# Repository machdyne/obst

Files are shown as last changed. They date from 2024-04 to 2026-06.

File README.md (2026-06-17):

# Obst Computer

Obst is an FPGA computer designed by Lone Dynamics Corporation.

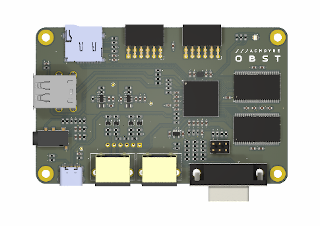
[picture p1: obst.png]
Obst


This repo will contain schematics, PCB layouts, pinouts, a 3D-printable case, example gateware and documentation.

Find more information on the [Obst product page](https://machdyne.com/product/obst-computer/).

## Programming Obst

Obst has a JTAG interface and ships with a [DFU bootloader](https://github.com/machdyne/tinydfu-bootloader) that allows the included flash [MMOD](https://machdyne.com/product/mmod) to be programmed over the USB-C port.

### DFU

The DFU bootloader is available for 5 seconds after power-on, issuing a DFU command during this period will stop the boot process until the DFU device is detached. If no command is received the boot process will continue and the user gateware will be loaded.

Install [dfu-util](http://dfu-util.sourceforge.net) (Debian/Ubuntu):

```
$ sudo apt install dfu-util
```

Update the user gateware on the flash MMOD:

```
$ sudo dfu-util -a 0 -D image.bit
```

Detach the DFU device and continue the boot process:

```
$ sudo dfu-util -a 0 -e
```

It is possible to update the bootloader itself using DFU but you shouldn't attempt this unless you have a JTAG programmer (or another method to program the MMOD) available, in case you need to restore the bootloader.

### JTAG

These examples assume you're using a "USB Blaster" JTAG cable, see the header pinout below. You will need to have [openFPGALoader](https://github.com/trabucayre/openFPGALoader) installed.

Program the configuration SRAM:

```
openFPGALoader -c usb-blaster image.bit
```

Program the flash MMOD:

```
openFPGALoader -f -c usb-blaster images/bootloader/tinydfu_obst.bit
```

## Blinky 

Building the blinky example requires [Yosys](https://github.com/YosysHQ/yosys), [nextpnr-ecp5](https://github.com/YosysHQ/nextpnr) and [Project Trellis](https://github.com/YosysHQ/prjtrellis).

Assuming they are installed, you can simply type `make` to build the gateware, which will be written to output/blinky.bin. You can then use [openFPGALoader](https://github.com/trabucayre/openFPGALoader) or dfu-util to write the gateware to the device.

## Zucker SOC

Obst can be used with [Zucker SOC](https://github.com/machdyne/zucker).

## JTAG Header

The 3.3V JTAG header can be used to program the FPGA SRAM as well as the MMOD flash memory. It can also be used to provide power (5V) to the board.

```
2 4 6
1 3 5
```

| Pin | Signal |
| --- | --- |
| 1 | TCK |
| 2 | TDI |
| 3 | TDO |
| 4 | TMS |
| 5 | 5V0 |
| 6 | GND |

## Board Revisions

| Revision | Notes |
| --- | ----- |
| V0A | Initial production version |
| V0B | Latest production version |

## License

The contents of this repo are released under the [Lone Dynamics Open License](LICENSE.md) with the following exceptions:

- The KiCad design files contain parts of the [kicad-pmod](https://github.com/mithro/kicad-pmod) library which is released under the [Apache License, Version 2.0](https://www.apache.org/licenses/LICENSE-2.0.html).

- The KiCad design files may contain symbols and footprints released under other licenses; please contact us if we've failed to give proper attribution.

Note: You can use these designs for commercial purposes but we ask that instead of producing exact clones, that you either replace our trademarks and logos with your own or add your own next to ours.

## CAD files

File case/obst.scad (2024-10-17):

/*
 * Obst Case
 * Copyright (c) 2024 Lone Dynamics Corporation. All rights reserved.
 *
 * required hardware:
 *  - 4 x M3 x 30mm countersunk bolts
 *  - 4 x M3 nuts
 * 
 */

$fn = 100;

board_width = 62;
board_thickness = 1.404;
board_length = 100;
board_height = 1.6;
board_spacing = 2;

wall = 1.5;

translate([2,2,-1.6]) mdr_board();

translate([0,0,0])
	mdr_case_top();

translate([0,0,-10])
	mdr_case_bottom();

module mdr_board() {
	
	difference() {
		union() {
			color([0,0.5,0])
				roundedcube(board_width,board_length,board_thickness, 4);

		}
		translate([4, 4, -1]) cylinder(d=3.2, h=100);
		translate([4, 96, -1]) cylinder(d=3.2, h=100);
		translate([58, 4, -1]) cylinder(d=3.2, h=100);
		translate([58, 96, -1]) cylinder(d=3.2, h=100);
	}	
		
}

module mdr_case_top() {

		translate([0,25,19])
				rotate([90,0,270])
					translate([-62.5,-10,0])
						linear_extrude(1)
							text("O B S T", size=4, halign="center",
								font="Liberation Sans:style=Bold");

		// addl supports
		translate([62,30.5+(14.5/2)+2,0]) cube([3.25,4,20]);
		translate([62,49.5+(14.5/2)+1.5,0]) cube([3.25,4.425,20]);
		translate([62,22.25,0]) cube([3.25,3,20]);

		translate([0,53.075,0]) cube([3.25,6.875,20]);
		translate([0,28.5,0]) cube([3.25,8.575,20]);

		translate([35,0,0]) cube([8.25,2.5,20]);
				
		translate([2,2,0]) {
			difference() {
				union() {
					translate([0,0,0]) cube([10,9,20]);
					translate([0,91.65,0]) cube([10,8.5,20]);
					translate([55,0,0]) cube([8,7.5,20]);
					translate([52,91.65,0]) cube([10,8.5,20]);
				}		

				// bolt holes
				translate([4,4,0]) cylinder(d=3.2, h=50);
				translate([4,96,0]) cylinder(d=3.2, h=50);
				translate([58,4,0]) cylinder(d=3.2, h=50);
				translate([58,96,0]) cylinder(d=3.2, h=50);
				
				translate([4,4,18.5]) cylinder(d=6, h=2);
				translate([4,96,18.5]) cylinder(d=6, h=2);
				translate([58,4,18.5]) cylinder(d=6, h=2);
				translate([58,96,18.5]) cylinder(d=6, h=2);

			}

		}
	
		difference () {
			
			// body			
			union() {
				roundedcube(board_width+4,board_length+4,20,5);
			}
			
			translate([2,2,-0.01]) {
				
				translate([0,0,0]) roundedcube(board_width,board_length,20-2,5);

				// vents
				translate([66/2-(15/2)-2,104/2-2-5,15]) rotate([0,0,-10]) cube([15,1,20]);
				translate([66/2-(15/2)-2,104/2-2,15]) rotate([0,0,-10]) cube([15,1,20]);
				translate([66/2-(15/2)-2,104/2-2+5,15]) rotate([0,0,-10]) cube([15,1,20]);		
				
				// LED vents
				translate([-10,86-5,3]) cube([25,1,1]);
				translate([-10,86,3]) cube([25,1,1]);
				translate([-10,86+5,3]) cube([25,1,1]);
				
				// PMODA
				translate([-10,43.075-(16/2),0]) cube([25,16,5.1]);

				// PMODB
				translate([-10,65.95-(16/2),0]) cube([25,16,5.1]);

				// sd card
				translate([-10,19-(15/2),0])
					cube([15,15,3]);

				// usb host
				translate([25.5-(15/2),-5,0])
					cube([15,10,16.25]);
				
				// audio jack
				translate([44.5-(6.5/2),-5,0])
					cube([6.5,10,6]);
	
				// VGA
				translate([55,76.175-(31/2),0]) cube([30,31,12.5]);
	
				// PS/2
				translate([55,30.5-(14.5/2),-2]) cube([30,14.5,13+2]);
				translate([55,49-(14.5/2),-2]) cube([30,14.5,13+2]);
				
				// usb-c
				translate([55,14-(9.5/2),0])
					cube([10,9.5,3.25]);

				// bolt holes
				translate([4,4,0]) cylinder(d=3.2, h=50);
				translate([4,96,0]) cylinder(d=3.2, h=50);
				translate([58,4,0]) cylinder(d=3.2, h=50);
				translate([58,96,0]) cylinder(d=3.2, h=50);
				
				translate([4,4,18.5]) cylinder(d=6, h=2);
				translate([4,96,18.5]) cylinder(d=6, h=2);
				translate([58,4,18.5]) cylinder(d=6, h=2);
				translate([58,96,18.5]) cylinder(d=6, h=2);
		
			}

		}				
		
}

module mdr_case_bottom() {

		difference () {
			
			union() {
				roundedcube(board_width+4,board_length+4,10,5);
			}
						
			translate([2,2,0]) {
				
				translate([8,-0.1,2]) roundedcube(board_width-8-8,board_length+0.2,10,5);
				translate([-0.25,8,2]) roundedcube(board_width+0.5,board_length-16,10,5);
			
				translate([-0.125,-0.125, 10-1.65])
					roundedcube(board_width+0.25,board_length+0.25, 10, 4);
				
				// bolt holes
				translate([4,4,0]) cylinder(d=3.2, h=50);
				translate([4,96,0]) cylinder(d=3.2, h=50);
				translate([58,4,0]) cylinder(d=3.2, h=50);
				translate([58,96,0]) cylinder(d=3.2, h=50);

				// nut holes
				translate([4,4,-1.75]) cylinder(d=7, h=4.5, $fn=6);
				translate([4,96,-1.75]) cylinder(d=7, h=4.5, $fn=6);
				translate([58,4,-1.75]) cylinder(d=7, h=4.5, $fn=6);
				translate([58,96,-1.75]) cylinder(d=7, h=4.5, $fn=6);


			}

		}
		
}

// https://gist.github.com/tinkerology/ae257c5340a33ee2f149ff3ae97d9826
module roundedcube(xx, yy, height, radius)
{
    translate([0,0,height/2])
    hull()
    {
        translate([radius,radius,0])
        cylinder(height,radius,radius,true);

        translate([xx-radius,radius,0])
        cylinder(height,radius,radius,true);

        translate([xx-radius,yy-radius,0])
        cylinder(height,radius,radius,true);

        translate([radius,yy-radius,0])
        cylinder(height,radius,radius,true);
    }
}

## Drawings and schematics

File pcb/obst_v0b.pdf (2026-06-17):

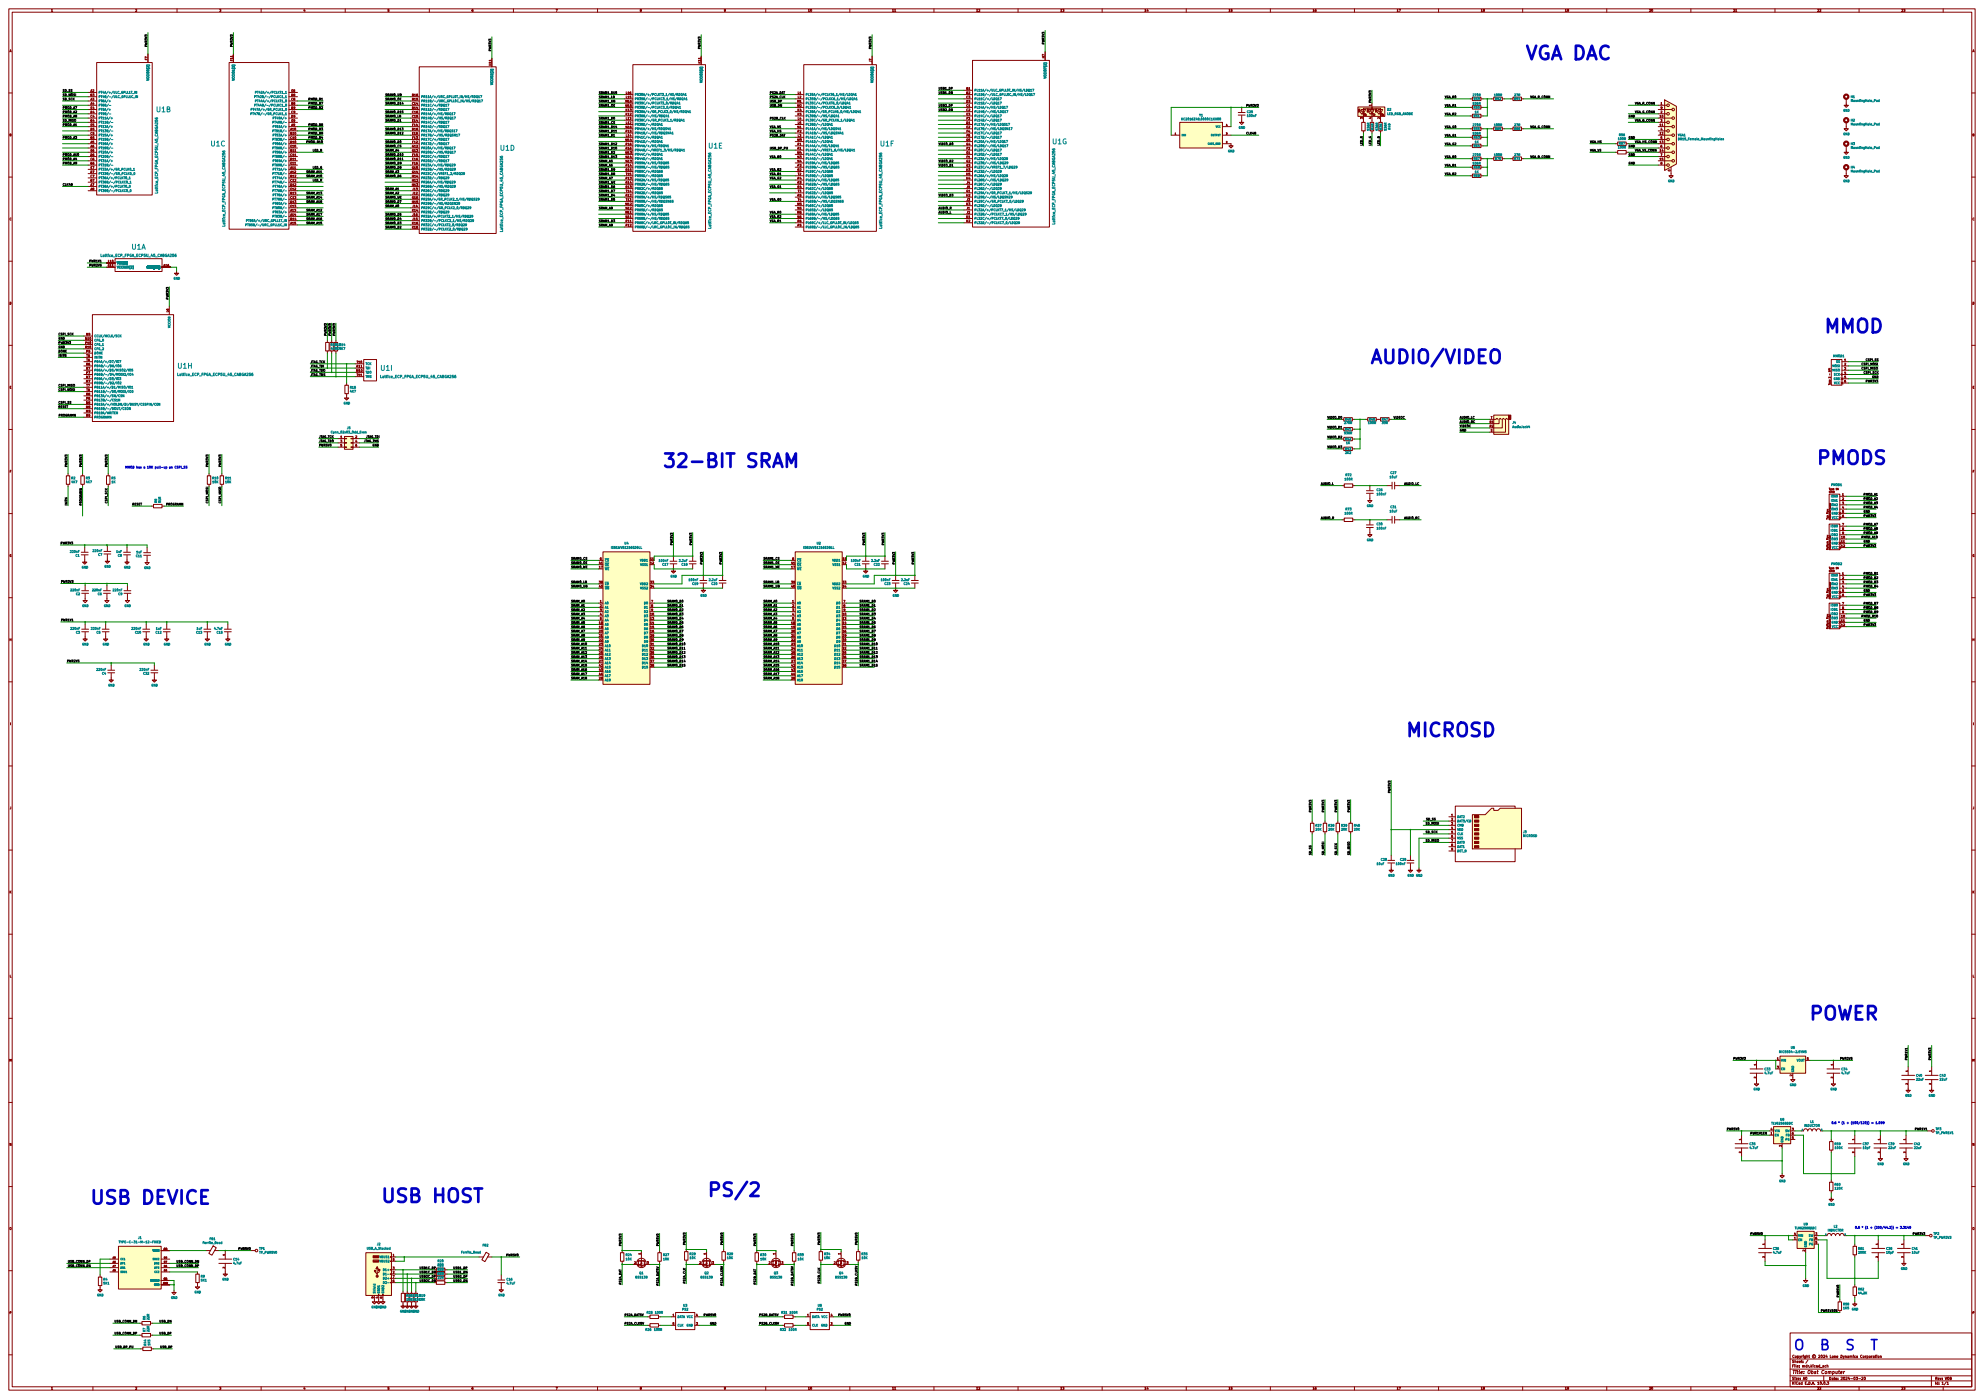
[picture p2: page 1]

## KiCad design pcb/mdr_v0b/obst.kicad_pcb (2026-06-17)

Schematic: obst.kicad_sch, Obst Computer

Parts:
C1, C2, C3, C4, C5, C6, C7, C9, C10, C32: 220nF; C_0603_1608Metric
C8, C11, C12, C13: 1uF; C_0603_1608Metric
C14, C15, C16, C33, C34, C35, C36: 4.7uF; C_0603_1608Metric
C17, C19, C21, C23, C25, C26, C29, C30: 100nF; C_0603_1608Metric
C18, C20, C22, C24: 2.2uF; C_0603_1608Metric
C27, C28, C31, C41: 10uF; C_0603_1608Metric
C37, C38: 10pF; C_0603_1608Metric
C39, C40, C42, C43: 22uF; C_0603_1608Metric
D2: LED_RGB_ANODE; LED_RGB_0606_CHANZON
FB1, FB2: Ferrite_Bead; R_0603_1608Metric
H1, H2, H3, H4: MountingHole_Pad; MountingHole_3.2mm_M3_Pad
J1: TYPE-C-31-M-12-FIXED; USB_C_Receptacle_HRO_TYPE-C-31-M-12-BIG-PADS; PARTREV A
J2: USB_A_Stacked; USB_A_Wuerth_61400826021_Horizontal_Stacked
J3: MICROSD; SDCARD
J4: AudioJack4; Jack_3.5mm_PJ320D_Horizontal
J5: Conn_02x03_Odd_Even; PinHeader_2x03_P2.54mm_Vertical
L1, L2: INDUCTOR; L_0805_2012Metric
MMOD1: PMOD-Device-x1-Type-2-SPI; MMOD_Host_Socket
PMOD1, PMOD2: PMOD-Device-x2-Type-1A-GPIO; PMOD_2x06_HOST
Q1, Q2, Q3, Q4: BSS138; SOT-323_SC-70
R2, R3, R12, R13, R14, R15: 4K7; R_0603_1608Metric
R4, R9: 5K1; R_0603_1608Metric
R5, R42, R51, R64, R69: 1K; R_0603_1608Metric
R6, R7, R20, R21, R22, R23: 22R; R_0603_1608Metric
R8: 51R; R_0603_1608Metric
R10, R11, R24, R27, R28, R29, R30, R33, R34, R35: 10K; R_0603_1608Metric
R16, R17, R18, R19: 15K; R_0603_1608Metric
R25, R26, R31, R32, R46, R52, R56, R57, R65, R70, R72, R73: 100R; R_0603_1608Metric
R36, R41, R48, R49, R50, R63, R68: 536R; R_0603_1608Metric
R37, R38, R39, R45: 20K; R_0603_1608Metric
R40, R53, R55, R67: 270R; R_0603_1608Metric
R43: 2K2; R_0603_1608Metric
R44, R58: 1K5; R_0603_1608Metric
R47: 33R; R_0603_1608Metric
R54, R66, R71: 27R; R_0603_1608Metric
R59: 100K; R_0603_1608Metric
R60: 120K; R_0603_1608Metric
R61: 200K; R_0603_1608Metric
R62: 44.2K; R_0603_1608Metric
TP1: TP_PWR5V0; TestPoint_THTPad_D1.0mm_Drill0.5mm
TP2: TP_PWR3V3; TestPoint_THTPad_D1.0mm_Drill0.5mm
TP3: TP_PWR1V1; TestPoint_THTPad_D1.0mm_Drill0.5mm
U1: Lattice_ECP_FPGA_ECP5U_45_CABGA256; BGA-256_14.0x14.0mm_Layout16x16_P0.8mm_Ball0.45mm_Pad0.32mm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
U2, U4: IS61WV51216EDBLL; TSOP-II-44_10.16x18.41mm_P0.8mm
U3, U5: PS2; MINI-DIN-6-FULL-SHIELD
U6: MIC5504-2.5YM5; SOT-23-5
U8, U9: TLV62568DDC; SOT-23-6
VGA1: DB15_Female_MountingHoles; DSUB-15-HD_Female_Horizontal_P2.29x1.98mm_EdgePinOffset3.03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
Y1: KC2016Z48.0000C1KX00; OSC_KC2016Z13.5600C1KX00; PARTREV November 2020

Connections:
/AUDIO_L: R72.1, U1.J2 (PL32B/-/PCLKC7_1/HS/LDQ29)
/AUDIO_LC: C27.2, J4.T
/AUDIO_R: R73.1, U1.J1 (PL32A/+/PCLKT7_1/HS/LDQ29)
/AUDIO_RC: C31.2, J4.R1
/CLK48: U1.A7 (PT38A/+/PCLKT0_0), Y1.3 (OUTPUT)
/CSPI_MISO: MMOD1.3 (MISO), R11.2, U1.T7 (PB11A/+/D1/MISO/IO1)
/CSPI_MOSI: MMOD1.2 (MOSI), R10.2, U1.T8 (PB11B/-/D0/MOSI/IO0)
/CSPI_SCK: MMOD1.4 (SCK), R5.2, U1.N9 (CCLK/MCLK/SCK)
/CSPI_SS: MMOD1.1 (SS), U1.N8 (PB15A/+/HOLDN/DI/BUSY/CSSPIN/CEN)
/DONE: U1.P9 (DONE)
/INITN: R2.2, U1.T9 (INITN)
/JTAG_TCK: J5.1, R15.1, U1.T10 (TCK)
/JTAG_TDI: J5.2, R12.2, U1.R11 (TDI)
/JTAG_TDO: J5.3, R13.2, U1.M10 (TDO)
/JTAG_TMS: J5.4, R14.2, U1.T11 (TMS)
/LED_B: R49.1, U1.B11 (PT58A/+)
/LED_G: R36.1, U1.A11 (PT71A/+)
/LED_R: R48.1, U1.C12 (PT74B/-)
/PMOD_A1: PMOD1.1 (IOA0), U1.E5 (PT13A/+)
/PMOD_A2: PMOD1.2 (IOA1), U1.D4 (PT9B/-)
/PMOD_A3: PMOD1.3 (IOA2), U1.B5 (PT15B/-)
/PMOD_A4: PMOD1.4 (IOA3), U1.C6 (PT31A/+)
/PMOD_A7: PMOD1.7 (IOB0), U1.E4 (PT9A/+)
/PMOD_A8: PMOD1.8 (IOB1), U1.C4 (PT11A/+)
/PMOD_A9: PMOD1.9 (IOB2), U1.B6 (PT31B/-)
/PMOD_A10: PMOD1.10 (IOB3), U1.D6 (PT20B/-)
/PMOD_B1: PMOD2.1 (IOA0), U1.C8 (PT44A/+/PCLKT1_0)
/PMOD_B2: PMOD2.2 (IOA1), U1.B9 (PT47A/+/GR_PCLK1_0)
/PMOD_B3: PMOD2.3 (IOA2), U1.A10 (PT51B/-)
/PMOD_B4: PMOD2.4 (IOA3), U1.C10 (PT53B/-)
/PMOD_B7: PMOD2.7 (IOB0), U1.B8 (PT44B/-/PCLKC1_0)
/PMOD_B8: PMOD2.8 (IOB1), U1.A9 (PT51A/+)
/PMOD_B9: PMOD2.9 (IOB2), U1.B10 (PT53A/+)
/PMOD_B10: PMOD2.10 (IOB3), U1.D10 (PT56A/+)
/PROGRAMN: R3.2, R8.2, U1.R9 (PROGRAMN)
/PS2A_CLK: Q2.2 (S), R28.2, U1.L2 (PL35B/-/PCLKC6_1/HS/LDQ41)
/PS2A_CLK5V: Q2.3 (D), R26.1, R29.2
/PS2A_DAT: Q1.2 (S), R24.2, U1.L1 (PL35A/+/PCLKT6_1/HS/LDQ41)
/PS2A_DAT5V: Q1.3 (D), R25.1, R27.2
/PS2B_CLK: Q4.2 (S), R34.2, U1.L4 (PL38C/+/GR_PCLK6_1/LDQ41)
/PS2B_CLK5V: Q4.3 (D), R32.1, R35.2
/PS2B_DAT: Q3.2 (S), R30.2, U1.L3 (PL41C/+/LDQ41)
/PS2B_DAT5V: Q3.3 (D), R31.1, R33.2
/PWR1V1: C3.2, C5.2, C10.2, C12.2, C13.2, C15.2, C37.1, C39.1, C40.1, C42.1, L1.2, R59.1, TP3.1, U1.G6 (VCC[6]), U1.G7 (VCC[6]), U1.G9 (VCC[6]), U1.L8 (VCC[6]), U1.L9 (VCC[6]), U1.L10 (VCC[6])
/PWR1V1EN: R58.2, U8.1 (EN), U9.5 (PG)
/PWR2V5: C4.2, C32.2, C34.1, U1.G11 (VCCAUX[2]), U1.L7 (VCCAUX[2]), U6.5 (VOUT)
/PWR3V3: C1.2, C2.2, C6.2, C7.2, C8.2, C9.2, C11.2, C17.2, C18.2, C19.2, C20.2, C21.2, C22.2, C23.2, C24.2, C25.1, C28.1, C29.1, C33.1, C38.1, C41.1, C43.1, D2.1 (A), J3.4 (VDD), L2.2, MMOD1.6 (VCC), PMOD1.6 (VCC), PMOD1.12 (VCC), PMOD2.6 (VCC), PMOD2.12 (VCC), Q1.1 (G), Q2.1 (G), Q3.1 (G), Q4.1 (G), R2.1, R3.1, R5.1, R10.1, R11.1, R12.1, R13.1, R14.1, R24.1, R28.1, R30.1, R34.1, R37.1, R38.1, R39.1, R45.1, R61.1, TP2.1, U1.F6 (VCCIO0[2]), U1.F7 (VCCIO0[2]), U1.F10 (VCCIO1[2]), U1.F11 (VCCIO1[2]), U1.H6 (VCCIO7[2]), U1.H7 (VCCIO7[2]), U1.H11 (VCCIO2[2]), U1.J6 (VCCIO6[2]), U1.J7 (VCCIO6[2]), U1.J11 (VCCIO2[2]), U1.K11 (VCCIO3[2]), U1.L6 (VCCIO8), U1.L11 (VCCIO3[2]), U1.P10 (CFG_1), U2.11 (VDD1), U2.33 (VDD2), U4.11 (VDD1), U4.33 (VDD2), U6.1 (VIN), U6.3 (EN), Y1.1 (INH), Y1.4 (VCC)
/PWR5V0: C14.1, C16.1, C35.1, C36.1, FB1.1, FB2.1, J5.5, R27.1, R29.1, R33.1, R35.1, R58.1, TP1.1, U3.4 (VCC), U5.4 (VCC), U8.4 (VIN), U9.1 (EN), U9.4 (VIN)
/RESET: R8.1, U1.M8 (PB15B/-/DOUT/CSON)
/SD_MISO: J3.7 (DAT0), R45.2, U1.B4 (PT11B/-)
/SD_MOSI: J3.3 (CMD), R38.2, U1.B3 (PT4B/-/ULC_GPLL1C_IN)
/SD_SCK: J3.5 (CLK), R39.2, U1.A3 (PT6A/+)
/SD_SS: J3.2 (DAT3/CD), R37.2, U1.A2 (PT4A/+/ULC_GPLL1T_IN)
/SRAM0_CS: U1.G12 (PR20A/+/HS/RDQ17), U4.6 (~CS)
/SRAM0_D0: U1.F12 (PR17D/-/RDQ17), U4.7 (D0)
/SRAM0_D1: U1.E14 (PR14C/+/RDQ17), U4.8 (D1)
/SRAM0_D2: U1.K15 (PR32D/-/PCLKC2_0/RDQ29), U4.9 (D2)
/SRAM0_D3: U1.K16 (PR32C/+/PCLKT2_0/RDQ29), U4.10 (D3)
/SRAM0_D4: U1.J15 (PR32B/-/PCLKC2_1/HS/RDQ29), U4.13 (D4)
/SRAM0_D5: U1.J16 (PR32A/+/PCLKT2_1/HS/RDQ29), U4.14 (D5)
/SRAM0_D6: U1.H14 (PR23D/-/RDQ29), U4.15 (D6)
/SRAM0_D7: U1.H15 (PR29B/-/HS/RDQSN29), U4.16 (D7)
/SRAM0_D8: U1.G15 (PR23B/-/HS/RDQ29), U4.29 (D8)
/SRAM0_D9: U1.F16 (PR23A/+/HS/RDQ29), U4.30 (D9)
/SRAM0_D10: U1.F15 (PR20C/+/RDQ17), U4.31 (D10)
/SRAM0_D11: U1.E16 (PR20D/-/RDQ17), U4.32 (D11)
/SRAM0_D12: U1.E15 (PR17B/-/HS/RDQSN17), U4.35 (D12)
/SRAM0_D13: U1.D16 (PR17A/+/HS/RDQS17), U4.36 (D13)
/SRAM0_D14: U1.C14 (PR11C/+/RDQ17), U4.37 (D14)
/SRAM0_D15: U1.C16 (PR14A/+/HS/RDQ17), U4.38 (D15)
/SRAM0_LB: U1.C15 (PR14B/-/HS/RDQ17), U4.39 (~LB)
/SRAM0_OE: U1.B15 (PR11B/-/URC_GPLL0C_IN/HS/RDQ17), U4.41 (~OE)
/SRAM0_UB: U1.B16 (PR11A/+/URC_GPLL0T_IN/HS/RDQ17), U4.40 (~UB)
/SRAM0_WE: U1.G16 (PR29A/+/GR_PCLK2_1/HS/RDQS29), U4.17 (~WE)
/SRAM1_CS: U1.L12 (PR38D/-/RDQ41), U2.6 (~CS)
/SRAM1_D0: U1.L13 (PR38C/+/GR_PCLK3_1/RDQ41), U2.7 (D0)
/SRAM1_D1: U1.L14 (PR41C/+/RDQ41), U2.8 (D1)
/SRAM1_D2: U1.M13 (PR44C/+/RDQ41), U2.9 (D2)
/SRAM1_D3: U1.P11 (PR68C/+/LRC_GPLL0T_IN/RDQ65), U2.10 (D3)
/SRAM1_D4: U1.R12 (PR65A/+/HS/RDQS65), U2.13 (D4)
/SRAM1_D5: U1.T13 (PR65B/-/HS/RDQSN65), U2.14 (D5)
/SRAM1_D6: U1.R13 (PR62C/+/RDQ65), U2.15 (D6)
/SRAM1_D7: U1.T14 (PR62D/-/RDQ65), U2.16 (D7)
/SRAM1_D8: U1.T15 (PR59D/-/RDQ65), U2.29 (D8)
/SRAM1_D9: U1.R15 (PR59C/+/RDQ65), U2.30 (D9)
/SRAM1_D10: U1.R16 (PR44B/-/VREF1_3/HS/RDQ41), U2.31 (D10)
/SRAM1_D11: U1.P15 (PR41B/-/HS/RDQSN41), U2.32 (D11)
/SRAM1_D12: U1.P16 (PR44A/+/HS/RDQ41), U2.35 (D12)
/SRAM1_D13: U1.N14 (PR44D/-/RDQ41), U2.36 (D13)
/SRAM1_D14: U1.N16 (PR41A/+/HS/RDQS41), U2.37 (D14)
/SRAM1_D15: U1.L16 (PR35A/+/PCLKT3_1/HS/RDQ41), U2.38 (D15)
/SRAM1_LB: U1.L15 (PR35B/-/PCLKC3_1/HS/RDQ41), U2.39 (~LB)
/SRAM1_OE: U1.M15 (PR35D/-/PCLKC3_0/RDQ41), U2.41 (~OE)
/SRAM1_UB: U1.M16 (PR35C/+/PCLKT3_0/RDQ41), U2.40 (~UB)
/SRAM1_WE: U1.R14 (PR62B/-/HS/RDQ65), U2.17 (~WE)
/SRAM_A0: U1.J14 (PR29C/+/GR_PCLK2_0/RDQ29), U2.1 (A0), U4.1 (A0)
/SRAM_A1: U1.J13 (PR26C/+/RDQ29), U2.2 (A1), U4.2 (A1)
/SRAM_A2: U1.J12 (PR26D/-/RDQ29), U2.3 (A2), U4.3 (A2)
/SRAM_A3: U1.G14 (PR23C/+/VREF1_2/RDQ29), U2.4 (A3), U4.4 (A3)
/SRAM_A4: U1.G13 (PR20B/-/HS/RDQ17), U2.5 (A4), U4.5 (A4)
/SRAM_A5: U1.N13 (PR59A/+/HS/RDQ65), U2.18 (A5), U4.18 (A5)
/SRAM_A6: U1.P14 (PR59B/-/HS/RDQ65), U2.19 (A6), U4.19 (A6)
/SRAM_A7: U1.P13 (PR62A/+/HS/RDQ65), U2.20 (A7), U4.20 (A7)
/SRAM_A8: U1.P12 (PR68D/-/LRC_GPLL0C_IN/RDQ65), U2.21 (A8), U4.21 (A8)
/SRAM_A9: U1.N12 (PR65D/-/RDQ65), U2.22 (A9), U4.22 (A9)
/SRAM_A10: U1.B12 (PT74A/+), U2.23 (A10), U4.23 (A10)
/SRAM_A11: U1.A12 (PT71B/-), U2.24 (A11), U4.24 (A11)
/SRAM_A12: U1.A13 (PT83A/+), U2.25 (A12), U4.25 (A12)
/SRAM_A13: U1.B13 (PT78A/+), U2.26 (A13), U4.26 (A13)
/SRAM_A14: U1.C13 (PT78B/-), U2.27 (A14), U4.27 (A14)
/SRAM_A15: U1.A15 (PT85B/-/URC_GPLL1C_IN), U2.42 (A15), U4.42 (A15)
/SRAM_A16: U1.B14 (PT85A/+/URC_GPLL1T_IN), U2.43 (A16), U4.43 (A16)
/SRAM_A17: U1.A14 (PT83B/-), U2.44 (A17), U4.44 (A17)
/SRAM_A18: U1.D13 (PT80A/+), U2.28 (A18), U4.28 (A18)
/USB1C_DN: J2.2 (D1-), R17.1, R21.2
/USB1C_DP: J2.3 (D1+), R16.1, R20.2
/USB1_DN: R21.1, U1.B2 (PL11B/-/ULC_GPLL0C_IN/HS/LDQ17)
/USB1_DP: R20.1, U1.B1 (PL11A/+/ULC_GPLL0T_IN/HS/LDQ17)
/USB2C_DN: J2.6 (D2-), R19.1, R23.2
/USB2C_DP: J2.7 (D2+), R18.1, R22.2
/USB2_DN: R23.1, U1.C2 (PL14B/-/HS/LDQ17)
/USB2_DP: R22.1, U1.C1 (PL14A/+/HS/LDQ17)
/USB_CONN_DN: J1.A7 (DN1), J1.B7 (DN2), R6.1
/USB_CONN_DP: J1.A6 (DP1), J1.B6 (DP2), R7.1
/USB_DN: R6.2, U1.M2 (PL35D/-/PCLKC6_0/LDQ41)
/USB_DP: R7.2, R44.2, U1.M1 (PL35C/+/PCLKT6_0/LDQ41)
/USB_DP_PU: R44.1, U1.R1 (PL44B/-/VREF1_6/HS/LDQ41)
/VGA_B0: R67.2, U1.N3 (PL44D/-/LDQ41)
/VGA_B1: R68.2, U1.T2 (PL59D/-/LDQ65)
/VGA_B2: R69.2, U1.R2 (PL59C/+/LDQ65)
/VGA_B_CONN: R71.1, VGA1.3
/VGA_G0: R55.2, U1.T4 (PL65B/-/HS/LDQSN65)
/VGA_G1: R63.2, U1.R4 (PL62C/+/LDQ65)
/VGA_G2: R64.2, U1.P4 (PL62A/+/HS/LDQ65)
/VGA_G_CONN: R66.1, VGA1.2
/VGA_HS: R56.2, U1.P2 (PL41B/-/HS/LDQSN41)
/VGA_HS_CONN: R56.1, VGA1.13
/VGA_R0: R53.2, U1.M6 (PL68A/+/HS/LDQ65)
/VGA_R1: R50.2, U1.P6 (PL68C/+/LLC_GPLL0T_IN/LDQ65)
/VGA_R2: R51.2, U1.N6 (PL68B/-/HS/LDQ65)
/VGA_R_CONN: R54.1, VGA1.1
/VGA_VS: R57.2, U1.N1 (PL41A/+/HS/LDQS41)
/VGA_VS_CONN: R57.1, VGA1.14
/VIDEOC: J4.R2, R47.2
/VIDEO_D0: R40.1, U1.G4 (PL20B/-/HS/LDQ17)
/VIDEO_D1: R41.1, U1.G3 (PL23C/+/VREF1_7/LDQ29)
/VIDEO_D2: R42.1, U1.G2 (PL23B/-/HS/LDQ29)
/VIDEO_D3: R43.1, U1.H2 (PL29B/-/HS/LDQSN29)
GND: C1.1, C2.1, C3.1, C4.1, C5.1, C6.1, C7.1, C8.1, C9.1, C10.1, C11.1, C12.1, C13.1, C14.2, C15.1, C16.2, C17.1, C18.1, C19.1, C20.1, C21.1, C22.1, C23.1, C24.1, C25.2, C26.2, C28.2, C29.2, C30.2, C32.1, C33.2, C34.2, C35.2, C36.2, C39.2, C40.2, C41.2, C42.2, C43.2, H1.1, H2.1, H3.1, H4.1, J1.A1 (GND), J1.A12 (GND), J1.B1 (GND), J1.B12 (GND), J1.S1 (SHIELD), J1.S2 (SHIELD), J1.S3 (SHIELD), J1.S4 (SHIELD), J2.4 (GND1), J2.8 (GND2), J2.9 (Shield), J3.6 (VSS), J4.S, J5.6, MMOD1.5 (GND), PMOD1.5 (GND), PMOD1.11 (GND), PMOD2.5 (GND), PMOD2.11 (GND), R4.2, R9.2, R15.2, R16.2, R17.2, R18.2, R19.2, R60.2, R62.2, U1.A1 (GND[27]), U1.A16 (GND[27]), U1.D2 (GND[27]), U1.D15 (GND[27]), U1.F8 (GND[27]), U1.F9 (GND[27]), U1.G8 (GND[27]), U1.G10 (GND[27]), U1.H1 (GND[27]), U1.H8 (GND[27]), U1.H9 (GND[27]), U1.H10 (GND[27]), U1.H16 (GND[27]), U1.J8 (GND[27]), U1.J9 (GND[27]), U1.J10 (GND[27]), U1.K6 (GND[27]), U1.K7 (GND[27]), U1.K8 (GND[27]), U1.K9 (GND[27]), U1.K10 (GND[27]), U1.N2 (GND[27]), U1.N10 (CFG_0), U1.N15 (GND[27]), U1.R10 (CFG_2), U1.T1 (GND[27]), U1.T5 (GND[27]), U1.T12 (GND[27]), U1.T16 (GND[27]), U2.12 (VSS1), U2.34 (VSS2), U3.3 (GND), U4.12 (VSS1), U4.34 (VSS2), U5.3 (GND), U6.2 (GND), U8.2 (GND), U9.2 (GND), VGA1.0 (PAD), VGA1.5, VGA1.6, VGA1.7, VGA1.8, VGA1.10, Y1.2 (CASE_GND)
unnamed: C26.1, C27.1, R72.2
unnamed: C30.1, C31.1, R73.2
unnamed: D2.2 (BK), R49.2
unnamed: D2.4 (GK), R36.2
unnamed: D2.3 (RK), R48.2
unnamed: FB1.2, J1.A4 (VBUS), J1.A9 (VBUS), J1.B4 (VBUS), J1.B9 (VBUS)
unnamed: J1.A5 (CC1), R4.1
unnamed: J1.B5 (CC2), R9.1
unnamed: FB2.2, J2.1 (VBUS1), J2.5 (VBUS2)
unnamed: R40.2, R41.2, R42.2, R43.2, R46.1
unnamed: R46.2, R47.1
unnamed: R50.1, R51.1, R52.2, R53.1
unnamed: R52.1, R54.2
unnamed: R55.1, R63.1, R64.1, R65.2
unnamed: R65.1, R66.2
unnamed: R67.1, R68.1, R69.1, R70.2
unnamed: R70.1, R71.2
unnamed: R26.2, U3.5 (CLK)
unnamed: R25.2, U3.1 (DATA)
unnamed: R32.2, U5.5 (CLK)
unnamed: R31.2, U5.1 (DATA)
unnamed: C37.2, R59.2, R60.1, U8.6 (FB)
unnamed: L1.1, U8.3 (SW)
unnamed: C38.2, R61.2, R62.1, U9.6 (FB)
unnamed: L2.1, U9.3 (SW)

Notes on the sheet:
0.6 * (1 + (100/120)) = 1.099
PS/2
POWER
0.6 * (1 + (200/44.2)) = 3.3149
VGA DAC
MMOD has a 10K pull-up on CSPI_SS
MICROSD
USB DEVICE
AUDIO/VIDEO
USB HOST
MMOD
PMODS
32-BIT SRAM
O B S T

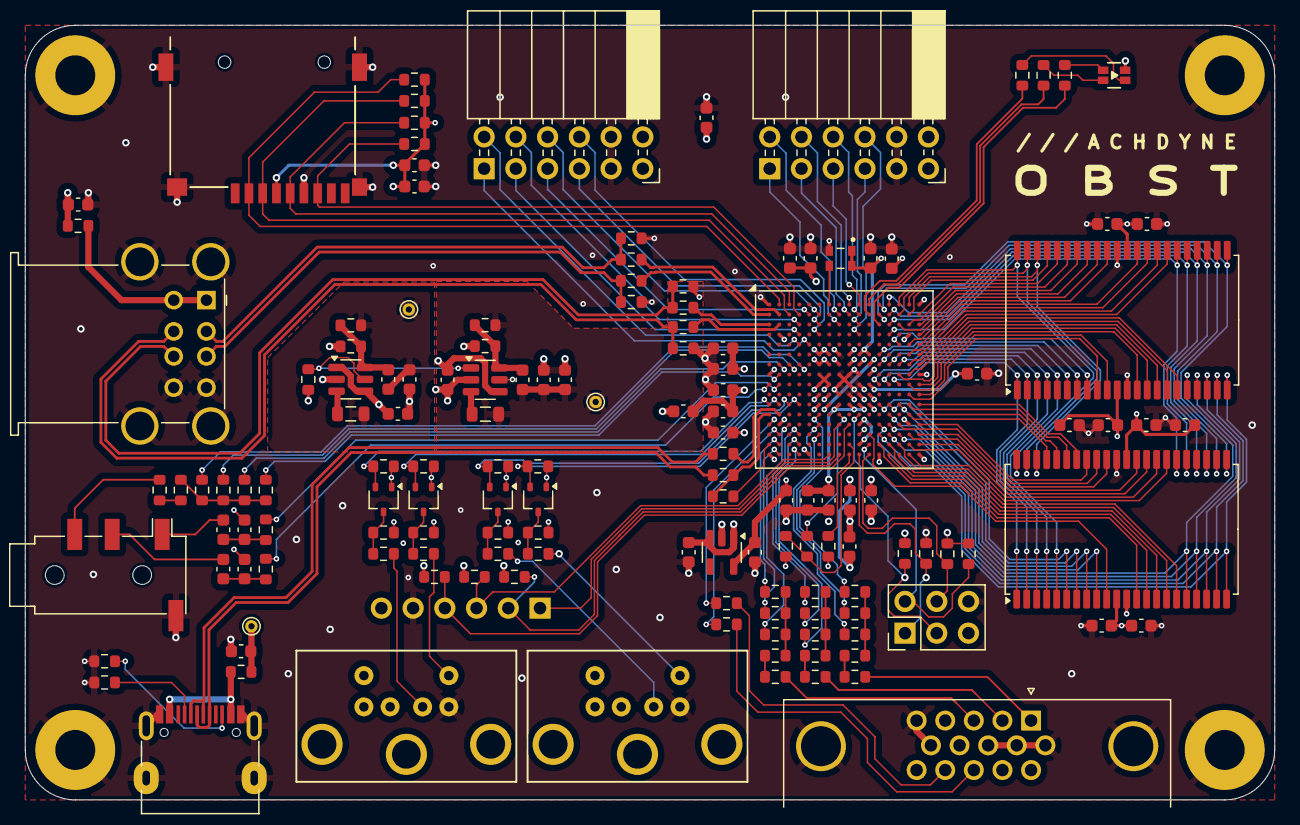
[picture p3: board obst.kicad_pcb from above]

Board: 4 copper layers, 100.0 x 62.0 mm, 149 parts (1 on the bottom side), 173 nets.

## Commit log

2024-04-26 add case
    [obst.scad]
2024-04-26 update case
    [obst.scad]
2024-10-17 add supports
    [obst.scad]
2026-06-17 add schematics and pcb layout
    [obst.kicad_pcb, obst.kicad_sch]

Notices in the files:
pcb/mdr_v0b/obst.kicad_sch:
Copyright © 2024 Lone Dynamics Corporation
